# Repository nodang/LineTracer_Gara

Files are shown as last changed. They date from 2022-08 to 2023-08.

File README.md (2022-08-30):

# 라인트레이서 <가라> / Line-follower GARA

단국대학교 MAZE 로봇연구회 소속의 스텝-라인트레이서

Line-follower with Stepper-Motor, which belongs Robot-Research-Society of MAZE from Dankook-Univ.

# 로봇 설명

라인트레이서는 검정 바탕의 경기장에 그려진 흰 색 라인을 따라서 움직이는 마이크로 로봇

라인트레이서는 다음과 같은 세 부분 구성

- 로봇의 위치와 라인의 형태를 판별하는 센서부

- 센서에서 수집된 데이터를 분석하여 제어 명령을 내리는 제어부

- 제어 명령을 수행하여 로봇의 이동을 담당하는 구동부

라인 트레이서는 로봇 제작을 처음 시작하고 어려워하는 사람들에게 추천되는 로봇입니다. 다른 로봇에 비해 접근이 쉽지만 깊이 들어갈수록 역학, 제어, 신호 처리 등 다양한 분야의 지식을 필요로 하게 되며 최단 경로를 찾는 알고리즘에 따라 로봇의 성능이 다르게 나타나게 됩니다.

따라서 라인트레이서는 폐곡선 내의 주행 기록을 단축시키는 것을 목표로 합니다.

# 1차 주행 - 가라

해당 영상은 2배속입니다.



# 2차 주행 - 가라

해당 영상은 2배속입니다.



# 2022 시립대 1차 주행 - 가라_2017

해당 영상은 1배속입니다.



# 2022 시립대 3차 주행 - 가라_2017

해당 영상은 1배속입니다.



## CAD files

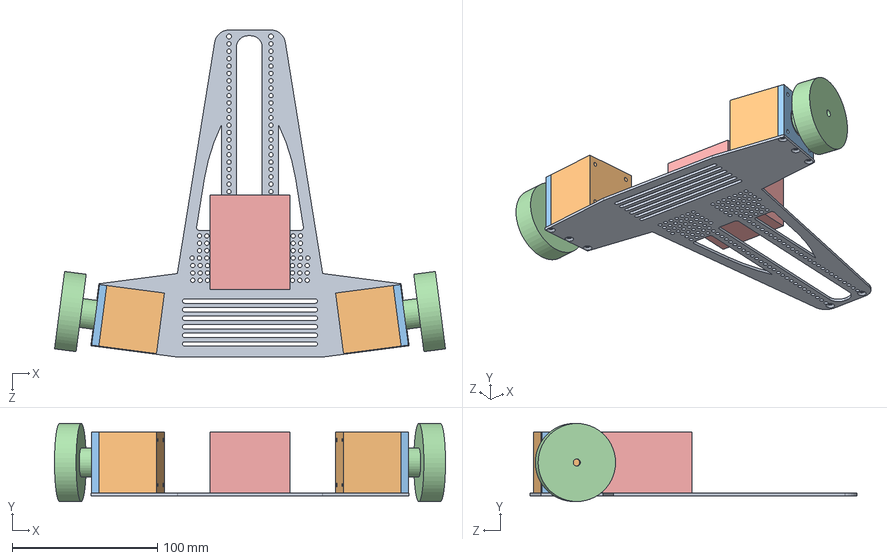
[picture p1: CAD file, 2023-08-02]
스텝 밑판/2021 트레이서.SLDASM
269.0 x 53.7 x 225.0 mm
2021_밑판
KH42JM2-901 x 2
가드 x 2
바퀴모형 x 2
배터리 모형

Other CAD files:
로컬 백업/git 이전 백업 자료/가가속도 이전 작업/PWM 이전 작업/20200813_1차 1700(40, 198)까지 완료/main/main.obj
로컬 백업/git 이전 백업 자료/가가속도 이전 작업/PWM 핸들 이전/20200910 4000이상 감소 계산 오류/main/main.obj
로컬 백업/git 이전 백업 자료/핸들 작업 시작전/210801백업_모터 저크가감속 코드 수정 완료(턴 저크 시작해야함)/main/main.obj
2809_가라_모니터/monitor2809/main/main.obj
2809_가라_17/main/main.obj
로컬 백업/git 이전 백업 자료/211227 턴마크 없애기 전/main/main.obj
로컬 백업/git 이전 백업 자료/핸들 작업 시작전/210718백업_핸들저크는 안되는데 ㅎㅎ/main/main.obj
로컬 백업/git 이전 백업 자료/가가속도 이전 작업/PWM 핸들 이전/20200827 PWM 소스 완성 직전(속도 조절 필요함)/main/main.obj
로컬 백업/git 이전 백업 자료/핸들 작업 시작전/210706백업_저크를이용한가감속완료_2차감속손봐야함_토크에 대한 고려가 빠짐/main/main.obj
로컬 백업/git 이전 백업 자료/가가속도 이전 작업/20210201 거의 다 됨 커브 손봐야함/main/main.obj
로컬 백업/git 이전 백업 자료/핸들 작업 시작전/210717백업_핸들소스구성전/main/main.obj
로컬 백업/git 이전 백업 자료/가가속도 이전 작업/202103언젠가 스탑 돌아가는거 고침, 핸들 고쳐야되는 상황/main/main.obj
로컬 백업/git 이전 백업 자료/핸들 작업 시작전/210709백업_기억나는건 가감속은 됐다는거/main/main.obj
2809_가라/main/main.obj
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

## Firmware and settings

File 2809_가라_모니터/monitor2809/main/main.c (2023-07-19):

//###########################################################################
//
// FILE:   MAIN.c
//
// TITLE:  MRSFAF main c file.
//
//###########################################################################
// $Release Date: 2011.10.5 $
//###########################################################################
#define __VARIABLE__
#define __STRUCT__

#include "DSP280x_Device.h"     // DSP280x Headerfile Include File
#include "DSP280x_Examples.h"   // DSP280x Examples Include File

#define MOTOR	(GpioDataRegs.GPADAT.all & 0x000000ff)	
#define SEN		(GpioDataRegs.GPADAT.all & 0x00701f00)


void Led_On(void)
{
	GpioDataRegs.GPBCLEAR.bit.GPIO33 = 1;
	//GpioDataRegs.GPBCLEAR.bit.GPIO34 = 1;
	GpioDataRegs.GPACLEAR.bit.GPIO13 = 1;
	GpioDataRegs.GPACLEAR.bit.GPIO27 = 1;
}

void Led_Off(void)
{
	GpioDataRegs.GPBSET.bit.GPIO33 = 1;
	//GpioDataRegs.GPBSET.bit.GPIO34 = 1;
	GpioDataRegs.GPASET.bit.GPIO13 = 1;
	GpioDataRegs.GPASET.bit.GPIO27 = 1;
}


void main(void)
{
	char RcvData;
	
	// Step 1. Initialize System Control:
	// PLL, WatchDog, enable Peripheral Clocks
	// This example function is found in the DSP280x_SysCtrl.c file.
	InitSysCtrl();

	// Step 2. Initalize GPIO: 
	// This example function is found in the DSP280x_Gpio.c file and
	// illustrates how to set the GPIO to it's default state.
	InitGpio();

	GpioDataRegs.GPACLEAR.all = MOTOR;
	GpioDataRegs.GPACLEAR.all = SEN;
	//GpioDataRegs.GPACLEAR.bit.GPIO8= 1;
	//GpioDataRegs.GPACLEAR.bit.GPIO20= 1;
	//GpioDataRegs.GPACLEAR.bit.GPIO21= 1;
	//GpioDataRegs.GPACLEAR.bit.GPIO22= 1;

	// Step 3. Clear all interrupts and initialize PIE vector table:
	// Disable CPU interrupts 
	DINT;
	
	MemCopy(&RamfuncsLoadStart, &RamfuncsLoadEnd, &RamfuncsRunStart);
	MemCopy(&RamfuncsLoadStart1, &RamfuncsLoadEnd1, &RamfuncsRunStart1);
	MemCopy(&Flash28_API_LoadStart, &Flash28_API_LoadEnd, &Flash28_API_RunStart);
	// Initialize the PIE control registers to their default state.
	// The default state is all PIE interrupts disabled and flags
	// are cleared.  
	// This function is found in the DSP280x_PieCtrl.c file.
	InitPieCtrl();

	// Disable CPU interrupts and clear all CPU interrupt flags:
	IER = 0x0000;
	IFR = 0x0000;

	// Initialize the PIE vector table with pointers to the shell Interrupt 
	// Service Routines (ISR).	
	// This will populate the entire table, even if the interrupt
	// is not used in this example.  This is useful for debug purposes.
	// The shell ISR routines are found in DSP280x_DefaultIsr.c.
	// This function is found in DSP280x_PieVect.c.
	InitPieVectTable();
	
	// The	RamfuncsLoadStart, RamfuncsLoadEnd, and RamfuncsRunStart
	// symbols are created by the linker. Refer to the F2808.cmd file. 

	// Call Flash Initialization to setup flash waitstates
	// This function must reside in RAM
	InitFlash();

	InitSystem();
	//InitLCD();
	VfdInit();
	//EnableInterrupts();

	// Enable global Interrupts and higher priority real-time debug events:
	//EINT;   // Enable Global interrupt INTM
	//ERTM;   // Enable Global realtime interrupt DBGM

	//Init_ISR();
	//EnableInterrupts();

	//Led_Off();

	//StartCpuTimer1(); 
		
	VFDPrintf("-NODANG-");

	if(!SW_U) {
		StopCpuTimer1();
		//Led_Off();
		UserProgramStart();
	}
	else;

	PrintMenu();
	TxPrintf("\n[Monitor2809]#");

	while(1)
	{	
		//GpioDataRegs.GPACLEAR.bit.GPIO8= 1;
		//GpioDataRegs.GPACLEAR.bit.GPIO20= 1;
		//GpioDataRegs.GPACLEAR.bit.GPIO21= 1;
		//GpioDataRegs.GPACLEAR.bit.GPIO22= 1;
		
		RcvData = SCIx_RxChar();
		SCIx_TxChar(RcvData);

		switch(RcvData)
		{
			case 'M':
			case 'm':
				StopCpuTimer1();
				//Led_Off();
				PrintMenu();
				break;
				
			case 'A':
			case 'a':
				StopCpuTimer1();
				//Led_Off();
				TxPrintf("\n  Delete All Flash Sector.\n");
				DeleteAllFlash();
				break;
				
			case 'O':
			case 'o':
				StopCpuTimer1();
				//Led_Off();
				DeleteSecletFlash();
				break;
				
			case 'D':
			case 'd':
				StopCpuTimer1();
				//Led_Off();
				UserFlashErase_DownloadPrm();
				break;
				
			case 'G':
			case 'g':
				StopCpuTimer1();
				//Led_Off();
				UserProgramStart();
				break;

			case CR:
				StopCpuTimer1();
				//Led_Off();
				break;
				
			default:
				StopCpuTimer1();
				//Led_Off();
				TxPrintf("\n=======Wrong Command!!========\n");
				PrintMenu();
				break;
		}
		
		TxPrintf("\n[Monitor2809]#");
	}

}

void InitSystem(void)
{
	InitSci();
	//InitFlashAPI2808();
	InitFlashAPI2809();
}

void PrintMenu(void)
{
	TxPrintf("\n\n");
	TxPrintf("========   TMS320F2809 Monitor V1.0   ========\n");	
	TxPrintf("  M  :	Display Menu.\n");
	TxPrintf("  A  :	Delete All Flash.( Sector B - D )\n");
	TxPrintf("  O  :	Delete Select Sector Flash. ( ex. O B )\n");
	TxPrintf("  D  :	User Sector Flash Erase & DownLoad User Program ( *.Hex )\n");
	TxPrintf("  G  :	Go User Program\n");
	TxPrintf("========   by Hwang Ha-yun Maze 8th   ========\n");	
	TxPrintf("========  blog.naver.com/hhyjjang.do  ========\n\n");
	TxPrintf("=======  CPU_2809 25th NODANG Monitor  =======\n");
}

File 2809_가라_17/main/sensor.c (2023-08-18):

//###########################################################################
//
// FILE		: Sensor.c
//
// TITLE	: Senser c file.
//
// Author	:  Yuk Keun Ho
//
// Company	: Maze & Hz
//
//###########################################################################
// $Release Date: 2011.12.10 $
//###########################################################################

#include "DSP280x_Device.h"
#include "DSP280x_Examples.h"   // DSP280x Examples Include File
#include "DSP280x_SWPrioritizedIsrLevels.h"
#include "Main.h"
#include "Sensor.h"

#define MAX_PID		12.0

#define MAX_POSITION	12000
#define MAX_STRAIGHT	1000

#define MIN_MAXMIN		1024.0

// ADC CHANNEL SORTING
Uint32 adc_prog[16] = {	adc_channel0,	adc_channel1,	adc_channel2,	adc_channel3,
						adc_channel4,	adc_channel5,	adc_channel6,	adc_channel7,
						adc_channel8,	adc_channel9,	adc_channel10,	adc_channel11,
						adc_channel12,	adc_channel13,	adc_channel14,	adc_channel15	};

// SENSOR POSTION SORTING
Uint32 sensor_prog[8] = { SEN0, SEN1, SEN2, SEN3, SEN4, SEN5, SEN6, SEN7 };

Uint16 state_table[19] = 
{	0x000f , 0x000f , 0x000f, 
	0x000f ,  // 0000 0000 0000 1111
	0x001e ,  // 0000 0000 0001 1110
	0x003c ,  // 0000 0000 0011 1100
	0x0078 ,  // 0000 0000 0111 1000   
	0x00f0 ,  // 0000 0000 1111 0000
	0x01e0 ,  // 0000 0001 1110 0000
	0x03c0 ,  // 0000 0011 1100 0000
	0x0780 ,  // 0000 0111 1000 0000   
	0x0f00 ,  // 0000 1111 0000 0000
	0x1e00 ,  // 0001 1110 0000 0000
	0x3c00 ,  // 0011 1100 0000 0000
	0x7800 ,  // 0111 1000 0000 0000
	0xf000 ,  // 1111 0000 0000 0000
	0xf000 , 0xf000 , 0xf000  	};

void Init_SENSOR()
{
	Uint16 count = 0;

	//SENSOR OFF
	GpioDataRegs.GPACLEAR.all = SENall;
	LED_R_OFF;
	LED_L_OFF;
	Flag.Sensor_U16 = OFF;

	memset((void *)SenAdc.Adc_U16,0x00,sizeof(Uint16)*16);
	memset((void *)SenAdc.Div127_U16,0x00,sizeof(Uint16)*16);
	memset((void *)SenAdc.AdcValue_U16,0x00,sizeof(Uint16)*16);
	memset((void *)ARROW_ACTIVE_U16,0x00,sizeof(Uint16)*16);
	memset((void *)ARROW_PASSIVE_U16,0x00,sizeof(Uint16)*16);
	memset((void *)POSITION_WEIGHT_I32,0x00,sizeof(int32)*16);
 
	SENSOR_COUNT = 0;
	LINE_OUT_U16 = 0;
	SENSOR_ENABLE = 0x0000;
	SENSOR_STATE_U16 = 0x0000;
	SENSOR_STATE_U16_CNT = 0;
	

	// POSITION RESET
	SenAdc.Position_U16_CNT = 6;
	SenAdc.Position_IQ10 = _IQ10(0.0);
	SenAdc.PositionTemporary_IQ10 = _IQ10(0.0);
	SenAdc.PositionShift_IQ10 = _IQ10(0.0);

	
	// POSITION WEIGHT		D * 10 um
	POSITION_WEIGHT_I32[0]	= 12000;	ARROW_ACTIVE_U16[0]	= 0x0001;	ARROW_PASSIVE_U16[0] = 0xfffe;	//	0000 0000 0000 0001
	POSITION_WEIGHT_I32[1]	= 10400;	ARROW_ACTIVE_U16[1]	= 0x0002;	ARROW_PASSIVE_U16[1] = 0xfffd;	//	0000 0000 0000 0010
	POSITION_WEIGHT_I32[2]	= 8800;		ARROW_ACTIVE_U16[2]	= 0x0004;	ARROW_PASSIVE_U16[2] = 0xfffb;	//	0000 0000 0000 0100
	POSITION_WEIGHT_I32[3]	= 7200;		ARROW_ACTIVE_U16[3]	= 0x0008;	ARROW_PASSIVE_U16[3] = 0xfff7;	//	0000 0000 0000 1000

	POSITION_WEIGHT_I32[4]	= 5550;		ARROW_ACTIVE_U16[4]	= 0x0010;	ARROW_PASSIVE_U16[4] = 0xffef;	//	0000 0000 0001 0000
	POSITION_WEIGHT_I32[5]	= 3950;		ARROW_ACTIVE_U16[5]	= 0x0020;	ARROW_PASSIVE_U16[5] = 0xffdf;	//	0000 0000 0010 0000
	POSITION_WEIGHT_I32[6]	= 2350;		ARROW_ACTIVE_U16[6]	= 0x0040;	ARROW_PASSIVE_U16[6] = 0xffbf;	//	0000 0000 0100 0000
	POSITION_WEIGHT_I32[7]	= 750;		ARROW_ACTIVE_U16[7]	= 0x0080;	ARROW_PASSIVE_U16[7] = 0xff7f;	//	0000 0000 1000 0000

	POSITION_WEIGHT_I32[8]	= -750;		ARROW_ACTIVE_U16[8]	= 0x0100;	ARROW_PASSIVE_U16[8] = 0xfeff;	//	0000 0001 0000 0000
	POSITION_WEIGHT_I32[9]	= -2350;	ARROW_ACTIVE_U16[9]	= 0x0200;	ARROW_PASSIVE_U16[9] = 0xfdff;	//	0000 0010 0000 0000
	POSITION_WEIGHT_I32[10]	= -3950;	ARROW_ACTIVE_U16[10]= 0x0400;	ARROW_PASSIVE_U16[10]= 0xfbff;	//	0000 0100 0000 0000
	POSITION_WEIGHT_I32[11]	= -5550;	ARROW_ACTIVE_U16[11]= 0x0800;	ARROW_PASSIVE_U16[11]= 0xf7ff;	//	0000 1000 0000 0000

	POSITION_WEIGHT_I32[12]	= -7200;	ARROW_ACTIVE_U16[12]= 0x1000;	ARROW_PASSIVE_U16[12]= 0xefff;	//	0001 0000 0000 0000
	POSITION_WEIGHT_I32[13]	= -8800;	ARROW_ACTIVE_U16[13]= 0x2000;	ARROW_PASSIVE_U16[13]= 0xdfff;	//	0010 0000 0000 0000
	POSITION_WEIGHT_I32[14]	= -10400;	ARROW_ACTIVE_U16[14]= 0x4000;	ARROW_PASSIVE_U16[14]= 0xbfff;	//	0100 0000 0000 0000
	POSITION_WEIGHT_I32[15]	= -12000;	ARROW_ACTIVE_U16[15]= 0x8000;	ARROW_PASSIVE_U16[15]= 0x7fff;	//	1000 0000 0000 0000

	for(count = 0; count < 16; count++)		{ SenAdc.MaxminusMin_IQ17[count]		= (((long)SenAdc.Max_U16[count]) << 17)		- (((long)SenAdc.Min_U16[count])<< 17); }

}

interrupt void SENSOR_ISR() 
{
	PieCtrlRegs.PIEACK.all = PIEACK_GROUP1;

	// 중요함 현재 실행중인 인터럽트 그룹이 우선적으로 실행되도록 함
	// 자세한 내용은 https://software-dl.ti.com/C2000/docs/c28x_interrupt_nesting/html/index.html 참고
	IER &= MINT1;
	EINT;

	if(Flag.Sensor_U16)	
	{
		GpioDataRegs.GPASET.all = sensor_prog[SENSOR_COUNT];
		
		AdcRegs.ADCCHSELSEQ1.all = adc_prog[SENSOR_COUNT];
		AdcRegs.ADCCHSELSEQ2.all = adc_prog[SENSOR_COUNT + 8];
		AdcRegs.ADCCHSELSEQ3.all = adc_prog[SENSOR_COUNT];
		AdcRegs.ADCCHSELSEQ4.all = adc_prog[SENSOR_COUNT + 8];
	
		AdcRegs.ADCTRL2.bit.SOC_SEQ1 = 1;		// ADC interrupt Start
	}
}
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

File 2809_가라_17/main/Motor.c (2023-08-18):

//###########################################################################
//
// FILE		: Motor.c
//
// TITLE	: Motor c file.
//
// Author	: Yuk Keun Ho
//
// Company	: Maze & Hz
//
//###########################################################################
// $Release Date: 2011.10.16 $
//###########################################################################

#define _MOTOR_

#include "DSP280x_Device.h"
#include "DSP280x_Examples.h"   // DSP280x Examples Include File
#include "DSP280x_SWPrioritizedIsrLevels.h"
#include "Main.h"
#include "Motor.h"

void Init_MOTOR()
{	
	memset((void *)&Flag,0x00,sizeof(BITFLAG));
	memset((void *)&LMark,0x00,sizeof(TURNMARK));
	memset((void *)&RMark,0x00,sizeof(TURNMARK));
	memset((void *)&LMotor,0x00,sizeof(MOTORCTRL));
	memset((void *)&RMotor,0x00,sizeof(MOTORCTRL));

	CROSS_DISTANCE_IQ15 = _IQ15(0.0);
	
	// 모터 제어 환경 변수 초기화
	Init_MotorCtrl(&LMotor);
	Init_MotorCtrl(&RMotor);

	GpioDataRegs.GPADAT.all = MOTOR_DIR;
}

void Init_MotorCtrl(MOTORCTRL *pM)
{
	pM->PwmTBPRDdiv10000_IQ17 = _IQ24(MOTOR_PERIOD_MAXIMUMdiv10);
	pM->TargetHandle_IQ17 = _IQ17(1.0);	
}

inline void MOTOR_MOTION_VALUE(MOTORCTRL *pM, volatile struct EPWM_REGS *pEPWM)
{
	Uint16 clk = pEPWM->TBCTL.bit.CLKDIV;

	if(pM->NextVelocity_IQ17 < pM->TargetVel_IQ17) 
	{
		pM->NextVelocity_IQ17 += _IQ17mpy(_IQ14div(pM->NextAccel_IQ14, _IQ14(TEN_THOUSAND)) << 3, pM->PwmTBPRDdiv10000_IQ17);

		if(pM->NextVelocity_IQ17 >= pM->TargetVel_IQ17)
			pM->NextVelocity_IQ17 = pM->TargetVel_IQ17;

		pM->AccelLimit_IQ14 = MAX_ACC_IQ14 - (_IQ17mpy(ACC_GRADIENT_IQ17, pM->NextVelocity_IQ17) >> 3);
		
		pM->NextAccel_IQ14 += _IQ14mpy(pM->Jerk_IQ14, pM->PwmTBPRDdiv10000_IQ17 >> 3);

		if(pM->NextAccel_IQ14 > pM->AccelLimit_IQ14)
			pM->NextAccel_IQ14 = pM->AccelLimit_IQ14;

		pM->PrdNextTranSecon_IQ17 = _IQ17div(STEP_10000D_IQ17, pM->NextVelocity_IQ17);
	}
	else if(pM->NextVelocity_IQ17 > pM->TargetVel_IQ17)
	{
		pM->NextVelocity_IQ17 -= _IQ17mpyIQX(pM->DecelAccel_IQ14, 14, pM->PwmTBPRDdiv10000_IQ17, 17);

		if(pM->NextVelocity_IQ17 <= pM->TargetVel_IQ17)
			pM->NextVelocity_IQ17 = pM->TargetVel_IQ17;		

		pM->AccelLimit_IQ14 = MAX_ACC_IQ14 - (_IQ17mpy(ACC_GRADIENT_IQ17, pM->NextVelocity_IQ17) >> 3);

		if(pM->NextAccel_IQ14 > _IQ14(0.0))
			pM->NextAccel_IQ14 = _IQ14(0.0);

		pM->PrdNextTranSecon_IQ17 = _IQ17div(STEP_10000D_IQ17, pM->NextVelocity_IQ17);
	}
//--------------------------------------------------------------------------------------------------------------------------------------------------------------------------//

	pM->PwmTBPRDdiv10000_IQ17 = _IQ17mpy(pM->PrdNextTranSecon_IQ17, pM->TargetHandle_IQ17);

	if(pM->PwmTBPRDdiv10000_IQ17 <_IQ17(MOTOR_PERIOD_MINIMUMdiv10))			pM->PwmTBPRDdiv10000_IQ17 =_IQ17(MOTOR_PERIOD_MINIMUMdiv10);
	else if(pM->PwmTBPRDdiv10000_IQ17 >_IQ24(MOTOR_PERIOD_MAXIMUMdiv10))	pM->PwmTBPRDdiv10000_IQ17 =_IQ24(MOTOR_PERIOD_MAXIMUMdiv10);

	pM->RolEachStep_IQ17 = _IQ17div(CPUTIMER_2_PRDdiv10000mpySTEP_IQ17, pM->PwmTBPRDdiv10000_IQ17);

	if(pM->PwmTBPRDdiv10000_IQ17 < _IQ17(MOTOR_PERIOD_MINIMUMdiv10) << clk)
		while(pM->PwmTBPRDdiv10000_IQ17 < _IQ17(MOTOR_PERIOD_MINIMUMdiv10) << clk)
		{
			if(clk > 0)		clk--;
			else			break;
		}
	if(pM->PwmTBPRDdiv10000_IQ17 > _IQ17(MOTOR_PERIOD_MAXIMUMdiv10) << clk)
		while(pM->PwmTBPRDdiv10000_IQ17 > _IQ17(MOTOR_PERIOD_MAXIMUMdiv10) << clk)
		{
			if(clk < CLK_DIVISION_CONSTANT)		clk++;
			else								break;
		}
	pM->PrdNext_IQ14 = _IQ14mpyIQX(_IQ13(TEN_THOUSAND) >> clk, 13, pM->PwmTBPRDdiv10000_IQ17, 17);

	//pM->RolEachStep_IQ17			= _IQ17mpy(STEP_D_IQ17, _IQ17div(CPUTIMER_2_PRDdiv10000_IQ17, pM->PrdNextTranSecon_IQ17));
	pM->TurnMarkCheckDistance_IQ17 	+= pM->TurnMarkCheckDistance_IQ17 > _IQ17(16380.0) ? _IQ17(0.0) : STEP_D_IQ17;
	pM->CrossCheckDistance_IQ15		+= pM->CrossCheckDistance_IQ15 > _IQ15(32760.0) ? _IQ15(0.0) : STEP_D_IQ15;
	pM->GoneDistance_IQ15			+= pM->GoneDistance_IQ15 > _IQ15(16380.0) ? _IQ15(0.0) : STEP_D_IQ15;			// IQ17 셈 과정에 포함됨으로 16380으로 제한

	pM->ErrorDistance_IQ17 = pM->UserDistance_IQ17 - (pM->GoneDistance_IQ15 << 2);
	pM->ErrorDistance_IQ17 = pM->ErrorDistance_IQ17 < _IQ17(0.0) ? _IQ17(0.0) : pM->ErrorDistance_IQ17;

	pEPWM->TBCTL.bit.CLKDIV = clk;
	pEPWM->TBPRD = (Uint16)(pM->PrdNext_IQ14 >> 14);
	pEPWM->CMPA.half.CMPA = pEPWM->TBPRD >> 1;
}

void MOVE_TO_MOVE(_iq17 distance, _iq17 decel_distance, _iq17 target_velocity, _iq17 decel_velocity, _iq14 jerk, _iq14 decel_acc)
{	
	STOP_PWM_ISR();
	StopCpuTimer2();

	RMotor.TargetVel_IQ17 = LMotor.TargetVel_IQ17 = target_velocity;
	RMotor.Jerk_IQ14 = LMotor.Jerk_IQ14 = _IQ14div(jerk, _IQ14(TEN_THOUSAND));

	RMotor.DecelVelocity_IQ17 = LMotor.DecelVelocity_IQ17 = decel_velocity;
	RMotor.DecelDistance_IQ17 = LMotor.DecelDistance_IQ17 = decel_distance;
	RMotor.UserDistance_IQ17 = LMotor.UserDistance_IQ17 = distance;
	
	RMotor.ErrorDistance_IQ17 = RMotor.UserDistance_IQ17;
	LMotor.ErrorDistance_IQ17 = LMotor.UserDistance_IQ17;

	RMotor.DecelAccel_IQ14 = LMotor.DecelAccel_IQ14 = _IQ14div(decel_acc, _IQ14(TEN_THOUSAND));
	RMotor.DecelFlag_U16 = LMotor.DecelFlag_U16 = ON;

	StartCpuTimer2();
	START_PWM_ISR();
}

#define LIMIT_STOP_ACC	15000

void MOVE_TO_END(_iq17 distance)
{
	STOP_PWM_ISR();
	StopCpuTimer2();
	
	RMotor.TargetVel_IQ17 = LMotor.TargetVel_IQ17 = _IQ17(0.0);
	RMotor.DecelVelocity_IQ17 = LMotor.DecelVelocity_IQ17 = _IQ17(0.0);
	RMotor.DecelDistance_IQ17 = LMotor.DecelDistance_IQ17 =  _IQ17(HEIGHT_SEEN - 65.0);
	RMotor.UserDistance_IQ17 = LMotor.UserDistance_IQ17 = distance;

	RMotor.ErrorDistance_IQ17 = RMotor.UserDistance_IQ17;
	LMotor.ErrorDistance_IQ17 = LMotor.UserDistance_IQ17;

	RMotor.Jerk_IQ14 = LMotor.Jerk_IQ14 = _IQ14div(((long)JERK_U32) << 14, _IQ14(TEN_THOUSAND));

	// 2000 일때 최대 정지 가속도
	RMotor.DecelAccel_IQ14 = LMotor.DecelAccel_IQ14 = STOP_ACC_IQ14((RMotor.NextVelocity_IQ17 >> 1) + (LMotor.NextVelocity_IQ17 >> 1));

	if((RMotor.DecelAccel_IQ14 > _IQ14(LIMIT_STOP_ACC)) || (LMotor.DecelAccel_IQ14 > _IQ14(LIMIT_STOP_ACC)))
		RMotor.DecelAccel_IQ14 = LMotor.DecelAccel_IQ14 = _IQ14(LIMIT_STOP_ACC);
	else if((RMotor.DecelAccel_IQ14 < _IQ14(MIN_ACC)) || (LMotor.DecelAccel_IQ14 < _IQ14(MIN_ACC)))
		RMotor.DecelAccel_IQ14 = LMotor.DecelAccel_IQ14 = _IQ14(MIN_ACC);

	RMotor.DecelAccel_IQ14 = _IQ14div(RMotor.DecelAccel_IQ14, _IQ14(TEN_THOUSAND));
	LMotor.DecelAccel_IQ14 = _IQ14div(LMotor.DecelAccel_IQ14, _IQ14(TEN_THOUSAND));
	
	RMotor.DecelFlag_U16 = LMotor.DecelFlag_U16 = ON;

	StartCpuTimer2();
	START_PWM_ISR();
}

interrupt void LMOTOR_ISR()
{
	PieCtrlRegs.PIEACK.all = PIEACK_GROUP3;

	IER &= MINT3;
	EINT;
	
	L_PWM.ETCLR.bit.INT = 1;

	if(Flag.Motor_U16)
	{
		MOTOR_MOTION_VALUE(&LMotor, &L_PWM);
	}
}

interrupt void RMOTOR_ISR()
{
	PieCtrlRegs.PIEACK.all = PIEACK_GROUP3;

	IER &= MINT3;
	EINT;

	R_PWM.ETCLR.bit.INT = 1;

	if(Flag.Motor_U16)
	{
		MOTOR_MOTION_VALUE(&RMotor, &R_PWM);
	}
}
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

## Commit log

2022-01-03 2020년도 작업 코드
    [DSP280x_Adc.obj, DSP280x_CodeStartBranch.obj, DSP280x_CpuTimers.obj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]
2022-01-03 2021년도 작업 코드
    [DSP280x_Adc.obj, DSP280x_CodeStartBranch.obj, DSP280x_CpuTimers.obj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]
2022-01-03 로봇 밑판 솔리드웍스
    [2020.DWG, 2020_5.6도_밑판.SLDPRT, 2020_5.STL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]
2022-01-09 backup file used git before
    [DSP280x_Adc.obj, DSP280x_CodeStartBranch.obj, DSP280x_CpuTimers.obj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]
2022-06-09 chaenged motor's minimum velocity
    when it's moving minimum speed, stoped
    so, minimum vel is 300
    [DSP280x_Adc.obj, DSP280x_CodeStartBranch.obj, DSP280x_CpuTimers.obj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]
2022-06-12 codes refactoring and buzzer pin adding
    [DSP280x_Adc.obj, DSP280x_CodeStartBranch.obj, DSP280x_CpuTimers.obj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]
2022-06-23 Moved to the function of HANDLE in sensor to motor
    [DSP280x_Adc.obj, DSP280x_CodeStartBranch.obj, DSP280x_CpuTimers.obj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]
2022-06-27 sla7052m motor driver test sources
    [DSP280x_Adc.obj, DSP280x_CodeStartBranch.obj, DSP280x_CpuTimers.obj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]
2022-07-05 PWM control used SLA7052M
    [DSP280x_Adc.obj, DSP280x_CodeStartBranch.obj, DSP280x_CpuTimers.obj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]
2022-07-05 ready to third race
    [DSP280x_Adc.obj, DSP280x_CodeStartBranch.obj, DSP280x_CpuTimers.obj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]
2022-07-06 restore handle sources
    [DSP280x_Adc.obj, DSP280x_CodeStartBranch.obj, DSP280x_CpuTimers.obj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]
2022-07-09 clk change once
    1. stopping time raise
    2. clk changer restored with while in motor interrupt
    3. it's corrected that position pid was incorrect divided by 2
    [DSP280x_Adc.obj, DSP280x_CodeStartBranch.obj, DSP280x_CpuTimers.obj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]
2022-07-25 third test
    [DSP280x_Adc.obj, DSP280x_CodeStartBranch.obj, DSP280x_CpuTimers.obj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]
2022-07-26 third race 50per
    [2020_5.6도_밑판.STL, DSP280x_Adc.obj, DSP280x_CodeStartBranch.obj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]
2022-07-30 third race 80per
    [DSP280x_Adc.obj, DSP280x_CodeStartBranch.obj, DSP280x_CpuTimers.obj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]
2022-08-04 find vel compute err from jerk
    [DSP280x_Adc.obj, DSP280x_CodeStartBranch.obj, DSP280x_CpuTimers.obj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]
2022-08-04 err mark code add. compute a err mark once
    [DSP280x_Adc.obj, DSP280x_CodeStartBranch.obj, DSP280x_CpuTimers.obj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]
2022-08-07 changed body
    [DSP280x_Adc.obj, DSP280x_CodeStartBranch.obj, DSP280x_CpuTimers.obj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]
2022-08-09 add pwm interrupt to 가라 17
    [DSP280x_Adc.obj, DSP280x_CodeStartBranch.obj, DSP280x_CpuTimers.obj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]
2022-08-19 gara_17's third race added
    It's test version
    [DSP280x_Adc.obj, DSP280x_CodeStartBranch.obj, DSP280x_CpuTimers.obj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]
2022-08-19 gara's third race added
    it's test version
    [DSP280x_Adc.obj, DSP280x_CodeStartBranch.obj, DSP280x_CpuTimers.obj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]
2022-08-22 add s44s shift of the third race
    shift isn't soft and shift is applied only the short s44s
    [DSP280x_Adc.obj, DSP280x_CodeStartBranch.obj, DSP280x_CpuTimers.obj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]
2022-08-22 s44s speed up is 80% complete
    [DSP280x_Adc.obj, DSP280x_CodeStartBranch.obj, DSP280x_CpuTimers.obj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]
2022-08-22 s44s third race is complete
    [DSP280x_Adc.obj, DSP280x_CodeStartBranch.obj, DSP280x_CpuTimers.obj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]
2022-08-30 add image gif files
    [DSP280x_Adc.obj, DSP280x_CodeStartBranch.obj, DSP280x_CpuTimers.obj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]
2023-07-19 July 19, 2023. The linetracer Gara project is end.
    [DSP280x_Adc.obj, DSP280x_CodeStartBranch.obj, DSP280x_CpuTimers.obj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]
2023-07-29 July 30, 2023. test
    [DSP280x_Adc.obj, DSP280x_CodeStartBranch.obj, DSP280x_CpuTimers.obj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]
2023-07-29 July 30, 2023. Fixed Code.
    [DSP280x_Adc.obj, DSP280x_CodeStartBranch.obj, DSP280x_CpuTimers.obj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]
2023-07-30 July 31, 2023. Added IIR Filter at PID_HANDLE. And, moved HANDLE to Control interrupt from while
    [DSP280x_Adc.obj, DSP280x_CodeStartBranch.obj, DSP280x_CpuTimers.obj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]
2023-08-02 August 3, 2023. Handle test version 1
    [2021 트레이서.SLDASM, 2021_밑판 - 복사본.SLDPRT, 2021_밑판.DWG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]
2023-08-03 August 4, 2023. made new handle.
    [DSP280x_Adc.obj, DSP280x_CodeStartBranch.obj, DSP280x_CpuTimers.obj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]
2023-08-09 August 9, 2023. Fixed sources
    [DSP280x_Adc.obj, DSP280x_CodeStartBranch.obj, DSP280x_CpuTimers.obj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]
2023-08-15 August 15, 2023. 모터 인터럽트 수정 고려
    1. 3차 45-45-s 탈출 오류 수정
    [DSP280x_Adc.obj, DSP280x_CodeStartBranch.obj, DSP280x_CpuTimers.obj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]
2023-08-15 August 15, 2023. 3차 연속 45 전 직진일 때 s44s 계수가 아닌 sharp턴 계수를 사용하게 함
2023-08-15 August 15, 2023. 모터 pwm clk 변경시 틱틱 소리나는 현상 개선
    [DSP280x_Adc.obj, DSP280x_CodeStartBranch.obj, DSP280x_CpuTimers.obj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]
2023-08-15 August 15, 2023. 감속시 천천히 감속되는 문제 개선
2023-08-15 August 15, 2023. 감속도 에러 수정 및 모터 인터럽트 함수를 인라인으로 변경
    [DSP280x_Adc.obj, DSP280x_CodeStartBranch.obj, DSP280x_CpuTimers.obj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]
2023-08-15 August 15, 2023. 감속도를 미리 10000 나눈다
    [DSP280x_Adc.obj, DSP280x_CodeStartBranch.obj, DSP280x_CpuTimers.obj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]
2023-08-18 August 19, 2023. 시립대 전
    [DSP280x_Adc.obj, DSP280x_CodeStartBranch.obj, DSP280x_CpuTimers.obj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]
